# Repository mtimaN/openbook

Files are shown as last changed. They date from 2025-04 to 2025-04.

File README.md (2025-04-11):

# openbook
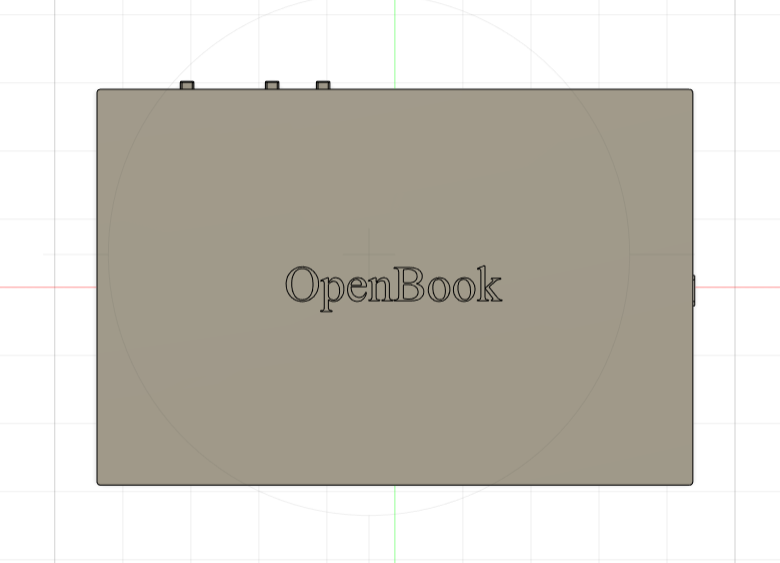
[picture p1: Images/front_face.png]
front_face

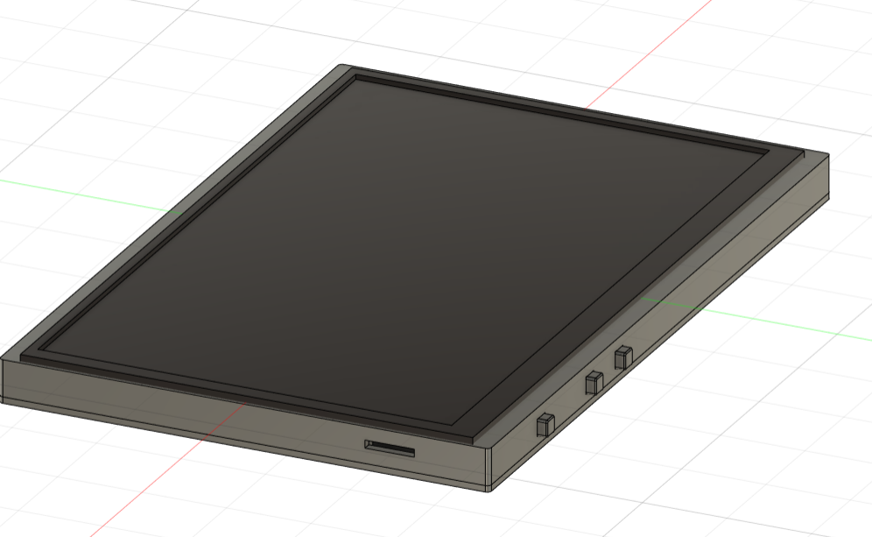
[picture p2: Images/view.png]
pretty_pic


## Overview
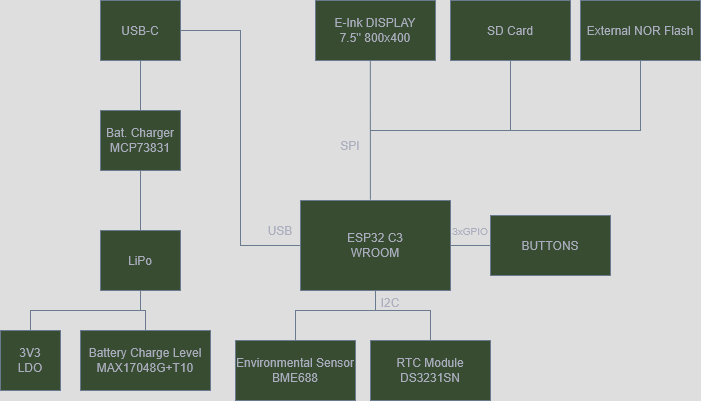
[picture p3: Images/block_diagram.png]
block_diagram


# 📚 eBook Reader – System Overview

This project is an eBook reader based on the ESP32-C3 microcontroller. It features a 7.5" E-Ink display, SD card storage, environmental sensing, and a rechargeable LiPo battery, all optimized for low power consumption and readability.

### **ESP32-C3 WROOM**
The main microcontroller that handles:
- Display updates via **SPI**
- File system and memory management
- Button inputs through **GPIO**
- Communication with sensors and RTC via **I2C**
- USB communication for firmware updates or data transfer

### **E-Ink DISPLAY 7.5" 800x400**
- Ultra-low power display ideal for reading in bright light
- Interface: SPI
- Controlled by the ESP32 for rendering text and images

###  Storage

- **SD Card**: Stores eBooks and data files
- **External NOR Flash**: Used for firmware, fonts, or static assets

### Power Management

- **USB-C**: Input for charging and potential USB data connection
- **Battery Charger (MCP73831)**: Manages LiPo charging
- **LiPo Battery**: Powers the system when unplugged
- **Battery Level Monitor (MAX17048G+T10)**: Reports battery percentage to the ESP32
- **3V3 LDO Regulator**: Provides stable 3.3V for the system

### **BME688 Sensor**
- Measures:
  - Temperature
  - Humidity
  - Pressure
  - Air quality
- Data can be displayed or logged for contextual awareness

### **DS3231SN RTC Module**
- Keeps track of time even when powered off
- Useful for:
  - Timestamps
  - Scheduled wake-ups
  - Time-based features
## ⚡ Energy Usage Overview

Estimated average current during typical reading:

| Component | Avg Current | Notes |
|---|---|---|
| ESP32-C3 | ~2 mA | Light sleep + brief active use |
| E-Ink Display | ~1–2 mA | Only draws power during refresh |
| SD Card | ~1 mA | Accessed briefly per page turn |
| BME688 Sensor | ~0.15 mA | In low-power mode |
| RTC DS3231SN | ~0.002 mA | Always running |
| Battery Monitor  | ~0.05 mA | Very low power |
| **Total** | **~5.2 mA** | Approximate average current |

With a **1200 mAh LiPo battery**:
- **Estimated runtime:** ~**9 days** of light usage
- Based on 1 screen update per minute, minimal background activity

## Bill of Materials (BOM) 
|SAMACSYS_PARTS_USB4110GFA|Value |Device |Detailed Description |Link |
|---|---|---|---|---|
|BOOT_BUTTON |BUTTON_CUSYOMV1 |BUTTON_CUSYOMV1 | |https://industry.panasonic.com/global/en/products/control/switch/light-touch/number/evqpuj02k |
|C1 |100nF |ESP32_WROVER_EAGLE-LTSPICE_CC0402 |CAPACITOR, European symbol |https://ro.mouser.com/ProductDetail/KYOCERA-AVX/12107C104KAT2A?qs=%252BdQmOuGyFcEpzvTfYF11Tg%3D%3D |
|C1_BAT |4.7uF |ESP32_WROVER_EAGLE-LTSPICE_CC0402 |CAPACITOR, European symbol |https://ro.mouser.com/ProductDetail/KYOCERA-AVX/12107C104KAT2A?qs=%252BdQmOuGyFcEpzvTfYF11Tg%3D%3D |
|C1_BAT1 |4.7uF |ESP32_WROVER_EAGLE-LTSPICE_CC0402 |CAPACITOR, European symbol |https://ro.mouser.com/ProductDetail/KYOCERA-AVX/12107C104KAT2A?qs=%252BdQmOuGyFcEpzvTfYF11Tg%3D%3D |
|C1_BAT2 |4.7uF |EAGLE-LTSPICE_CC0402 |CAPACITOR, European symbol |https://ro.mouser.com/ProductDetail/KYOCERA-AVX/12107C104KAT2A?qs=%252BdQmOuGyFcEpzvTfYF11Tg%3D%3D |
|C2 |100nF |ESP32_WROVER_EAGLE-LTSPICE_CC0402 |CAPACITOR, European symbol |https://ro.mouser.com/ProductDetail/KYOCERA-AVX/12107C104KAT2A?qs=%252BdQmOuGyFcEpzvTfYF11Tg%3D%3D |
|C2_BAT |4.7uF |ESP32_WROVER_EAGLE-LTSPICE_CC0402 |CAPACITOR, European symbol |https://ro.mouser.com/ProductDetail/KYOCERA-AVX/12107C104KAT2A?qs=%252BdQmOuGyFcEpzvTfYF11Tg%3D%3D |
|C3 |100uF TANT |RCL_CPOL-EUCT3528 |POLARIZED CAPACITOR, European symbol |https://ro.mouser.com/ProductDetail/Panasonic/EEU-FS1K101L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 |
|C4 |4.7uF/25V |ESP32_WROVER_EAGLE-LTSPICE_CC0402 |CAPACITOR, European symbol |https://ro.mouser.com/ProductDetail/KYOCERA-AVX/12107C104KAT2A?qs=%252BdQmOuGyFcEpzvTfYF11Tg%3D%3D |
|C4_USB |100nF |ESP32_WROVER_EAGLE-LTSPICE_CC0402 |CAPACITOR, European symbol |https://ro.mouser.com/ProductDetail/KYOCERA-AVX/12107C104KAT2A?qs=%252BdQmOuGyFcEpzvTfYF11Tg%3D%3D |
|C5 |1uF |ESP32_WROVER_EAGLE-LTSPICE_CC0402 |CAPACITOR, European symbol |https://ro.mouser.com/ProductDetail/KYOCERA-AVX/12107C104KAT2A?qs=%252BdQmOuGyFcEpzvTfYF11Tg%3D%3D |
|C5_USB |4.7uF |ESP32_WROVER_EAGLE-LTSPICE_CC0402 |CAPACITOR, European symbol |https://ro.mouser.com/ProductDetail/KYOCERA-AVX/12107C104KAT2A?qs=%252BdQmOuGyFcEpzvTfYF11Tg%3D%3D |
|C6 |100nF |ESP32_WROVER_EAGLE-LTSPICE_CC0402 |CAPACITOR, European symbol |https://ro.mouser.com/ProductDetail/KYOCERA-AVX/12107C104KAT2A?qs=%252BdQmOuGyFcEpzvTfYF11Tg%3D%3D |
|C7 |10uF |ESP32_WROVER_EAGLE-LTSPICE_CC0402 |CAPACITOR, European symbol |https://ro.mouser.com/ProductDetail/KYOCERA-AVX/12107C104KAT2A?qs=%252BdQmOuGyFcEpzvTfYF11Tg%3D%3D |
|C8 |100nF |ESP32_WROVER_EAGLE-LTSPICE_CC0402 |CAPACITOR, European symbol |https://ro.mouser.com/ProductDetail/KYOCERA-AVX/12107C104KAT2A?qs=%252BdQmOuGyFcEpzvTfYF11Tg%3D%3D |
|C9 |100nF |EAGLE-LTSPICE_CC0402 |CAPACITOR, European symbol |https://ro.mouser.com/ProductDetail/KYOCERA-AVX/12107C104KAT2A?qs=%252BdQmOuGyFcEpzvTfYF11Tg%3D%3D |
|C10 |100nF |ESP32_WROVER_EAGLE-LTSPICE_CC0402 |CAPACITOR, European symbol |https://ro.mouser.com/ProductDetail/KYOCERA-AVX/12107C104KAT2A?qs=%252BdQmOuGyFcEpzvTfYF11Tg%3D%3D |
|C10_SUPERCAP |CPH3225A |CPH3225A |Cap 0.011F 3.3V 1210 Flat |https://ro.mouser.com/ProductDetail/Seiko-Semiconductors/CPH3225A?qs=3etwrb1wR%252BhUOph6lAO7eg%3D%3D |
|CHANGE_BUTTON |BUTTON_CUSYOMV1 |BUTTON_CUSYOMV1 | |https://industry.panasonic.com/global/en/products/control/switch/light-touch/number/evqpuj02k |
|CHG_LED | |ADAFRUIT_LEDCHIP-LED0603 |LED |https://ro.mouser.com/ProductDetail/BJB/35.116.1007-001-01?qs=iLKYxzqNS76jqQb6thkyzg%3D%3D |
|C_DELAY |100nF |ESP32_WROVER_EAGLE-LTSPICE_CC0402 |CAPACITOR, European symbol |https://ro.mouser.com/ProductDetail/KYOCERA-AVX/12107C104KAT2A?qs=%252BdQmOuGyFcEpzvTfYF11Tg%3D%3D |
|D1 |USBLC6-2SC6Y |USBLC6-2SC6Y |Low Cap. ESD Protection Auto SOT-23-6 STMicroelectronics USBLC6-2SC6Y, Dual Uni-Directional TVS Diode Array, 6-Pin SOT-23 |https://ro.mouser.com/ProductDetail/Nexperia/PMEG6030AEXEX?qs=olJun0bQHM8zqhEtOgE2ZA%3D%3D |
|D2 |ESP32_WROVER_AVX---SD0805S020S1R0_AVX_SD0805S020S1R0_0_0AVX_SD0805S020S1R0_0_0|ESP32_WROVER_AVX---SD0805S020S1R0_AVX_SD0805S020S1R0_0_0AVX_SD0805S020S1R0_0_0|Schottky Barrier Rectifier Diode |https://ro.mouser.com/ProductDetail/Nexperia/PMEG6030AEXEX?qs=olJun0bQHM8zqhEtOgE2ZA%3D%3D |
|D3 |MBR0530 |MBR0530 |ON SEMICONDUCTOR - MBR0530 - DIODE, SCHOTTKY, 0.5A, 30V, SOD-123 |https://ro.mouser.com/ProductDetail/Nexperia/PMEG6030AEXEX?qs=olJun0bQHM8zqhEtOgE2ZA%3D%3D |
|D4 |MBR0530 |MBR0530 |ON SEMICONDUCTOR - MBR0530 - DIODE, SCHOTTKY, 0.5A, 30V, SOD-123 |https://ro.mouser.com/ProductDetail/Nexperia/PMEG6030AEXEX?qs=olJun0bQHM8zqhEtOgE2ZA%3D%3D |
|D5 |MBR0530 |MBR0530 |ON SEMICONDUCTOR - MBR0530 - DIODE, SCHOTTKY, 0.5A, 30V, SOD-123 |https://ro.mouser.com/ProductDetail/Nexperia/PMEG6030AEXEX?qs=olJun0bQHM8zqhEtOgE2ZA%3D%3D |
|D6 |PGB1010603MR |PGB1010603MR |Check availability |https://ro.mouser.com/ProductDetail/Nexperia/PMEG6030AEXEX?qs=olJun0bQHM8zqhEtOgE2ZA%3D%3D |
|D7 |ESP32_WROVER_AVX---SD0805S020S1R0_AVX_SD0805S020S1R0_0_0AVX_SD0805S020S1R0_0_0|ESP32_WROVER_AVX---SD0805S020S1R0_AVX_SD0805S020S1R0_0_0AVX_SD0805S020S1R0_0_0|Schottky Barrier Rectifier Diode |https://ro.mouser.com/ProductDetail/Nexperia/PMEG6030AEXEX?qs=olJun0bQHM8zqhEtOgE2ZA%3D%3D |
|D8 |PGB1010603MR |PGB1010603MR |Schottky Barrier Rectifier Diode |https://ro.mouser.com/ProductDetail/Nexperia/PMEG6030AEXEX?qs=olJun0bQHM8zqhEtOgE2ZA%3D%3D |
|D9 |PGB1010603MR |PGB1010603MR |Schottky Barrier Rectifier Diode |https://ro.mouser.com/ProductDetail/Nexperia/PMEG6030AEXEX?qs=olJun0bQHM8zqhEtOgE2ZA%3D%3D |
|D10 |PGB1010603MR |PGB1010603MR |Schottky Barrier Rectifier Diode |https://ro.mouser.com/ProductDetail/Nexperia/PMEG6030AEXEX?qs=olJun0bQHM8zqhEtOgE2ZA%3D%3D |
|D11 |PGB1010603MR |PGB1010603MR |Schottky Barrier Rectifier Diode |https://ro.mouser.com/ProductDetail/Nexperia/PMEG6030AEXEX?qs=olJun0bQHM8zqhEtOgE2ZA%3D%3D |
|D12 |PGB1010603MR |PGB1010603MR |Schottky Barrier Rectifier Diode |https://ro.mouser.com/ProductDetail/Nexperia/PMEG6030AEXEX?qs=olJun0bQHM8zqhEtOgE2ZA%3D%3D |
|EPD_C1 |1uF/50V |ESP32_WROVER_EAGLE-LTSPICE_CC0402 |CAPACITOR, European symbol |https://ro.mouser.com/ProductDetail/KEMET/MMK10105K50A01L4BULK?qs=IKDMbYZLynBqWdM%252BAUSFtw%3D%3D |
|EPD_C2 |1uF/50V |ESP32_WROVER_EAGLE-LTSPICE_CC0402 |CAPACITOR, European symbol |https://ro.mouser.com/ProductDetail/KEMET/MMK10105K50A01L4BULK?qs=IKDMbYZLynBqWdM%252BAUSFtw%3D%3D |
|EPD_C5 |1uF/50V |ESP32_WROVER_EAGLE-LTSPICE_CC0402 |CAPACITOR, European symbol |https://ro.mouser.com/ProductDetail/KEMET/MMK10105K50A01L4BULK?qs=IKDMbYZLynBqWdM%252BAUSFtw%3D%3D |
|EPD_C6 |1uF/50V |ESP32_WROVER_EAGLE-LTSPICE_CC0402 |CAPACITOR, European symbol |https://ro.mouser.com/ProductDetail/KEMET/MMK10105K50A01L4BULK?qs=IKDMbYZLynBqWdM%252BAUSFtw%3D%3D |
|EPD_C7 |1uF/50V |ESP32_WROVER_EAGLE-LTSPICE_CC0402 |CAPACITOR, European symbol |https://ro.mouser.com/ProductDetail/KEMET/MMK10105K50A01L4BULK?qs=IKDMbYZLynBqWdM%252BAUSFtw%3D%3D |
|EPD_C8 |1uF/50V |ESP32_WROVER_EAGLE-LTSPICE_CC0402 |CAPACITOR, European symbol |https://ro.mouser.com/ProductDetail/KEMET/MMK10105K50A01L4BULK?qs=IKDMbYZLynBqWdM%252BAUSFtw%3D%3D |
|EPD_C9 |1uF/50V |ESP32_WROVER_EAGLE-LTSPICE_CC0402 |CAPACITOR, European symbol |https://ro.mouser.com/ProductDetail/KEMET/MMK10105K50A01L4BULK?qs=IKDMbYZLynBqWdM%252BAUSFtw%3D%3D |
|EPD_C10 |1uF/50V |ESP32_WROVER_EAGLE-LTSPICE_CC0402 |CAPACITOR, European symbol |https://ro.mouser.com/ProductDetail/KEMET/MMK10105K50A01L4BULK?qs=IKDMbYZLynBqWdM%252BAUSFtw%3D%3D |
|EPD_C11 |1uF/50V |ESP32_WROVER_EAGLE-LTSPICE_CC0402 |CAPACITOR, European symbol |https://ro.mouser.com/ProductDetail/KEMET/MMK10105K50A01L4BULK?qs=IKDMbYZLynBqWdM%252BAUSFtw%3D%3D |
|EPD_C12 |1uF/50V |ESP32_WROVER_EAGLE-LTSPICE_CC0402 |CAPACITOR, European symbol |https://ro.mouser.com/ProductDetail/KEMET/MMK10105K50A01L4BULK?qs=IKDMbYZLynBqWdM%252BAUSFtw%3D%3D |
|IC1 |BD5229G-TR |BD5229G-TR |Voltage Detector with Adjustable Delay Time: CMOS processes are utilized to develop high precision, low current consumption CMOS reset ICs that allow arbitrary setting of the delay time. The extensive lineup includes both Nch Open Drain and CMOS output types in a wide range of detection voltages (from 2.3V to 6.0V, in 0.1V steps), enabling selection of the ideal solution based on customer requirements. In addition, the entire series is of course both lead-free and RoHS-compliant.|https://ro.mouser.com/ProductDetail/ROHM-Semiconductor/BD5229G-TR?qs=4kLU8WoGk0vvnhrrYwdszw%3D%3D |
|IC4 |XC6220A331MR-G |XC6220A331MR-G |LDO Voltage Regulators | |
|J1 |FH34SRJ-24S-0.5SH_99_ |FH34SRJ-24S-0.5SH_99_ |24 Position FFC, FPC Connector Contacts, Top and Bottom 0.020 (0.50mm) Surface Mount, Right Angle" | |
|J2 |SAMACSYS_PARTS_USB4110-GF-A |SAMACSYS_PARTS_USB4110-GF-A |CONN USB 2.0 TYPE-C R/A SMT | |
|J3 |QWIIC_RIGHT_ANGLE |QWIIC_CONNECTORJS-1MM |SparkFun I2C Standard Qwiic Connector | |
|J4 |112A-TAAR-R03_ATTEND |112A-TAAR-R03_ATTEND |Micro SD Card Socket, Push-Push Type, Top Mount, SMT, H=1.83mm, 10u | |
|L1 |68uH |744043680IND_4828-WE-TPC_WRE | | |
|PFMF.050.1 |ESP32C6_VARISTORCN1812 |ESP32C6_VARISTORCN1812 |VARISTOR | |
|Q1 |20V/4.2A/52mO/1.4W |ESP32_WROVER_SPARKFUN-DISCRETESEMI_MOSFET_PCH-DMG2305UX-7 |P-channel MOSFETs | |
|Q2 |20V/4.2A/52mO/1.4W |ESP32_WROVER_SPARKFUN-DISCRETESEMI_MOSFET_PCH-DMG2305UX-7 |P-channel MOSFETs |https://ro.mouser.com/ProductDetail/Vishay-Siliconix/SQ3425CEV-T1_GE3?qs=i8QVZAFTkqQazbKSzWc2Vg%3D%3D |
|Q3 |SI1308EDL-T1-GE3 |SI1308EDL-T1-GE3 |MOSFET N-Ch 30V 1.5A TrenchFET SC70 Vishay Si1308EDL-T1-GE3 N-channel MOSFET Transistor, 1.5 A, 30 V, 3-Pin SC-70 |https://ro.mouser.com/ProductDetail/Vishay-Semiconductors/SI1308EDL-T1-GE3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 |
|R1 |10K |ESP32_WROVER_EAGLE-LTSPICE_RR0402 |RESISTOR, European symbol |https://ro.mouser.com/ProductDetail/Vishay-Beyschlag/MCS0402MD4703BE500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|
|R1-PINH |10K |ESP32_WROVER_EAGLE-LTSPICE_RR0402 |RESISTOR, European symbol |https://ro.mouser.com/ProductDetail/Vishay-Beyschlag/MCS0402MD4703BE500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|
|R1-PINH1 |10K |ESP32_WROVER_EAGLE-LTSPICE_RR0402 |RESISTOR, European symbol |https://ro.mouser.com/ProductDetail/Vishay-Beyschlag/MCS0402MD4703BE500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|
|R1_BAT |200 |ESP32_WROVER_EAGLE-LTSPICE_RR0402 |RESISTOR, European symbol |https://ro.mouser.com/ProductDetail/Vishay-Beyschlag/MCS0402MD4703BE500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|
|R1_PWRUSB |100K |ESP32_WROVER_EAGLE-LTSPICE_RR0402 |RESISTOR, European symbol |https://ro.mouser.com/ProductDetail/Vishay-Beyschlag/MCS0402MD4703BE500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|
|R2 |2.2 |ESP32_WROVER_EAGLE-LTSPICE_RR0402 |RESISTOR, European symbol |https://ro.mouser.com/ProductDetail/Vishay-Beyschlag/MCS0402MD4703BE500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|
|R2-PINH |10K |ESP32_WROVER_EAGLE-LTSPICE_RR0402 |RESISTOR, European symbol |https://ro.mouser.com/ProductDetail/Vishay-Beyschlag/MCS0402MD4703BE500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|
|R2-PINH1 |10K |ESP32_WROVER_EAGLE-LTSPICE_RR0402 |RESISTOR, European symbol |https://ro.mouser.com/ProductDetail/Vishay-Beyschlag/MCS0402MD4703BE500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|
|R2-USB |5k1 |ESP32_WROVER_EAGLE-LTSPICE_RR0402 |RESISTOR, European symbol |https://ro.mouser.com/ProductDetail/Vishay-Beyschlag/MCS0402MD4703BE500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|
|R2-USB1 |5k1 |ESP32_WROVER_EAGLE-LTSPICE_RR0402 |RESISTOR, European symbol |https://ro.mouser.com/ProductDetail/Vishay-Beyschlag/MCS0402MD4703BE500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|
|R2_BAT |2K |ESP32_WROVER_EAGLE-LTSPICE_RR0402 |RESISTOR, European symbol |https://ro.mouser.com/ProductDetail/Vishay-Beyschlag/MCS0402MD4703BE500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|
|R3 |10K |ESP32_WROVER_EAGLE-LTSPICE_RR0402 |RESISTOR, European symbol |https://ro.mouser.com/ProductDetail/Vishay-Beyschlag/MCS0402MD4703BE500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|
|R4 |10K |ESP32_WROVER_EAGLE-LTSPICE_RR0402 |RESISTOR, European symbol |https://ro.mouser.com/ProductDetail/Vishay-Beyschlag/MCS0402MD4703BE500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|
|R5 |10K |ESP32_WROVER_EAGLE-LTSPICE_RR0402 |RESISTOR, European symbol |https://ro.mouser.com/ProductDetail/Vishay-Beyschlag/MCS0402MD4703BE500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|
|R6 |10K |ESP32_WROVER_EAGLE-LTSPICE_RR0402 |RESISTOR, European symbol |https://ro.mouser.com/ProductDetail/Vishay-Beyschlag/MCS0402MD4703BE500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|
|R7 |10K |ESP32_WROVER_EAGLE-LTSPICE_RR0402 |RESISTOR, European symbol |https://ro.mouser.com/ProductDetail/Vishay-Beyschlag/MCS0402MD4703BE500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|
|R8 |10K |ESP32_WROVER_EAGLE-LTSPICE_RR0402 |RESISTOR, European symbol |https://ro.mouser.com/ProductDetail/Vishay-Beyschlag/MCS0402MD4703BE500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|
|R9 |10K |ESP32_WROVER_EAGLE-LTSPICE_RR0402 |RESISTOR, European symbol |https://ro.mouser.com/ProductDetail/Vishay-Beyschlag/MCS0402MD4703BE500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|
|R10 |10K |ESP32_WROVER_EAGLE-LTSPICE_RR0402 |RESISTOR, European symbol |https://ro.mouser.com/ProductDetail/Vishay-Beyschlag/MCS0402MD4703BE500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|
|RESET_BUTTON |BUTTON_CUSYOMV1 |BUTTON_CUSYOMV1 | |https://industry.panasonic.com/global/en/products/control/switch/light-touch/number/evqpuj02k |
|R_BOOT |10K |ESP32_WROVER_EAGLE-LTSPICE_RR0402 |RESISTOR, European symbol |https://ro.mouser.com/ProductDetail/Vishay-Beyschlag/MCS0402MD4703BE500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|
|R_CAPACITOR |15 |ESP32_WROVER_EAGLE-LTSPICE_RR0402 |RESISTOR, European symbol |https://ro.mouser.com/ProductDetail/Vishay-Beyschlag/MCS0402MD4703BE500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|
|R_CHANGE |10K |ESP32_WROVER_EAGLE-LTSPICE_RR0402 |RESISTOR, European symbol |https://ro.mouser.com/ProductDetail/Vishay-Beyschlag/MCS0402MD4703BE500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|
|R_CL1 |10K |ESP32_WROVER_EAGLE-LTSPICE_RR0402 |RESISTOR, European symbol |https://ro.mouser.com/ProductDetail/Vishay-Beyschlag/MCS0402MD4703BE500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|
|R_RESET |10K |ESP32_WROVER_EAGLE-LTSPICE_RR0402 |RESISTOR, European symbol |https://ro.mouser.com/ProductDetail/Vishay-Beyschlag/MCS0402MD4703BE500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|
|SENSOR2 | |ESP32_WROVER_BME680_BME680 |Integrated Environmental Unit |https://ro.mouser.com/ProductDetail/Bosch-Sensortec/BME680?qs=v271MhAjFHjo0yA%2FC4OnDQ%3D%3D |
|SJ1 | |SJ |SMD solder JUMPER |https://ro.mouser.com/ProductDetail/Nidec-Components/CJS-1201B?qs=XeJtXLiO41SSSa2Z7HG9Iw%3D%3D |
|TP1 |TPTP20R |TPTP20R |Test pad | |
|TP2 |TPTP20R |TPTP20R |Test pad | |
|TP3 |TPTP20R |TPTP20R |Test pad | |
|TP4 |TPTP20R |TPTP20R |Test pad | |
|TP5 |TPTP20R |TPTP20R |Test pad | |
|TP6 |TPTP20R |TPTP20R |Test pad | |
|TP7 |TPTP20R |TPTP20R |Test pad | |
|TP8 |TPTP20R |TPTP20R |Test pad | |
|TP9 |TPTP20R |TPTP20R |Test pad | |
|TP10 |TPTP20R |TPTP20R |Test pad | |
|TP11 |TPTP20R |TPTP20R |Test pad | |
|TP12 |TPTP20R |TPTP20R |Test pad | |
|TP13 |TPTP20R |TPTP20R |Test pad | |
|TP14 |TPTP20R |TPTP20R |Test pad | |
|TP15 |TPTP20R |TPTP20R |Test pad | |
|TP16 |TPTP20R |TPTP20R |Test pad | |
|TP17 |TPTP20R |TPTP20R |Test pad | |
|U1 |W25Q512JVEIQ |W25Q512JVEIQ | |https://ro.mouser.com/ProductDetail/Winbond/W25Q512JVEIQ?qs=l7cgNqFNU1jw6svr3at6tA%3D%3D |
|U2 |ESP32-C6-WROOM-1-N8 |ESP32-C6-WROOM-1-N8 | |https://ro.mouser.com/ProductDetail/Espressif-Systems/ESP32-C6-WROOM-1-N8?qs=8Wlm6%252BaMh8ST02Gmwp74cw%3D%3D |
|U3 |DS3231SN# |DS3231SN# | |https://ro.mouser.com/ProductDetail/Analog-Devices-Maxim-Integrated/DS3231SN?qs=1eQvB6Dk1vhUlr8%2FOrV0Fw%3D%3D |
|U4 |MAX17048G+T10 |MAX17048G+T10 | |https://ro.mouser.com/ProductDetail/Analog-Devices-Maxim-Integrated/MAX17048G%2bT10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 |
|U5 |MCP73831 |ESP32_WROVER_SPARKFUN-IC-POWER_MCP73831 |MCP73831T Li-Ion, Li-Pol Controller |https://ro.mouser.com/ProductDetail/Microchip-Technology/MCP73831T-2ACI-OT?qs=yUQqVecv4qvbBQBGbHx0Mw%3D%3D |

## Detailed description
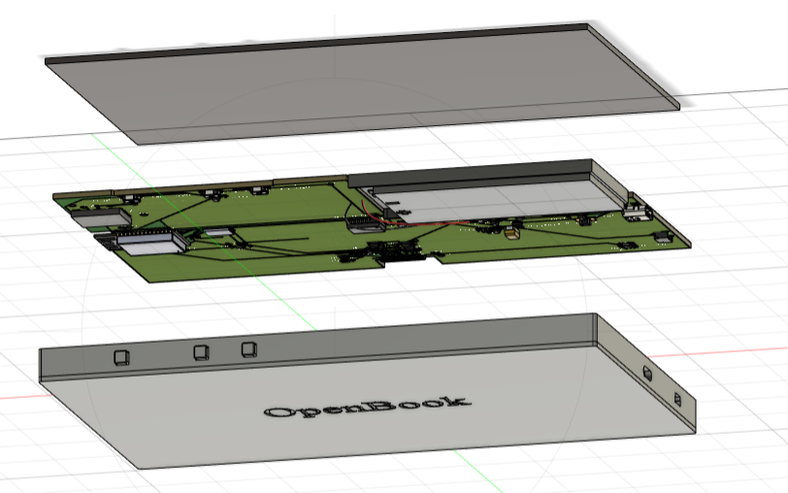
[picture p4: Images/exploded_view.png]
exploded_view


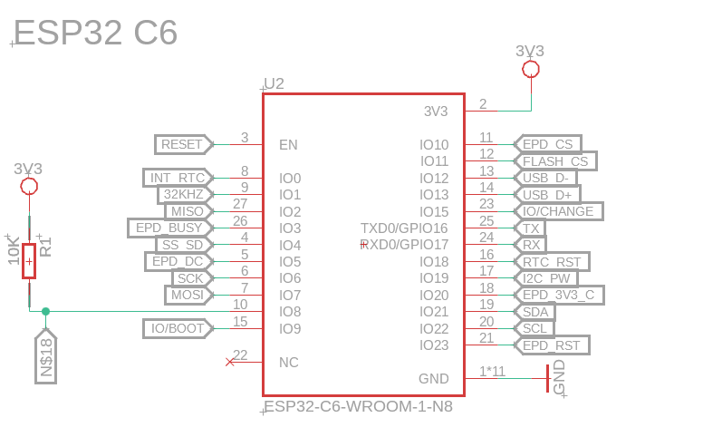
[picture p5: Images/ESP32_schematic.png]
esp32

- Resistor (R1) connected to GPIO8: This is a pull-up resistor connected to GPIO8. Pull-up resistors are used to ensure a pin has a defined high state when no external signal is applied.
- GPIO8: This is a general-purpose input/output pin. It can be configured as either an input or an output.
- IO/BOOT (Pin 15): This pin is used to put the ESP32-C6 into bootloader mode, which is necessary for flashing firmware.
- NC (Pin 22): This stands for "No Connection." This pin is not connected to anything in this particular circuit.
- EN (Pin 3): This is the Enable pin. Pulling this pin low resets the ESP32-C6.
- INT_RTC (Pin 8): This is likely an interrupt pin related to the Real-Time Clock (RTC) functionality.
- 32KHz (Pin 9): This is probably the input for a 32.768 kHz crystal oscillator, which is used for the RTC.
- MISO (Pin 27): This is the Master In Slave Out pin for the SPI (Serial Peripheral Interface) communication protocol.
- EPD_BUSY (Pin 4): This pin is likely used to signal the busy state of an E-Paper Display (EPD).
- SS_SD (Pin 5): This is the Slave Select pin for the SD card interface.
- EPD_DC (Pin 6): This is the Data/Command pin for the EPD.
- SCK (Pin 7): This is the Serial Clock pin for SPI communication.
- MOSI (Pin 10): This is the Master Out Slave In pin for SPI communication.
- 3V3 (Pin 2): This is another 3.3V power supply pin.
- IO10 to IO15 (Pins 11-14, 23): These are general-purpose input/output pins.
- TXD0/GPIO16 (Pin 24): This is the transmit pin for UART0 (Universal Asynchronous Receiver/Transmitter) and also functions as GPIO16.
- RXD0/GPIO17 (Pin 25): This is the receive pin for UART0 and also functions as GPIO17.
- RX (Pin 16): This is likely another receive pin, possibly for a second UART.
- RTC_RST (Pin 17): This is the reset pin for the RTC.
- I2C_PW (Pin 12): This pin might be related to powering the I2C (Inter-Integrated Circuit) bus.
- IO18 to IO23 (Pins 18-21): These are general-purpose input/output pins.
- EPD_3V3_C (Pin 19): This is likely a 3.3V power supply pin specifically for the EPD.
- SDA (Pin 20): This is the Serial Data pin for I2C communication.
- SCL (Pin 21): This is the Serial Clock pin for I2C communication.
- EPD_RST (Pin 21): This is the reset pin for the EPD.
- 1*11 (Pin 1): This indicates that pin 1 is connected to ground (GND).

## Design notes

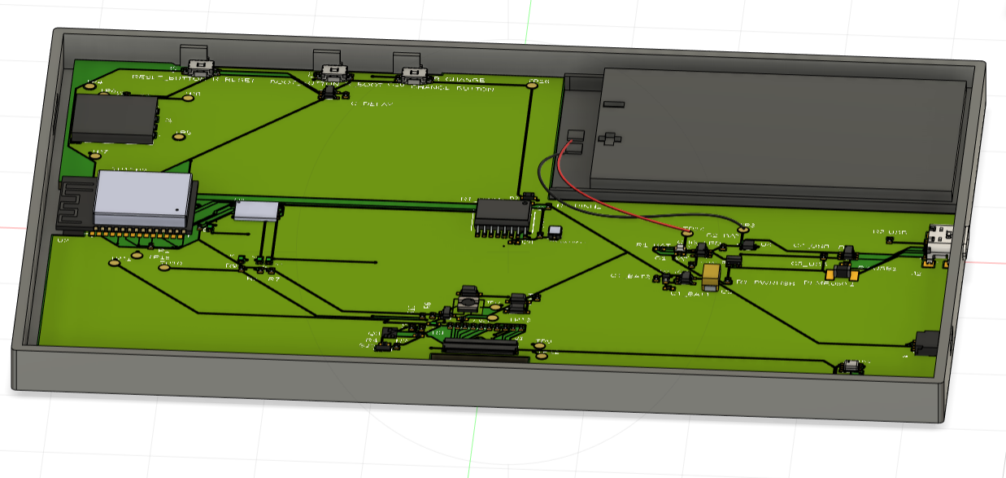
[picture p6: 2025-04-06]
Images/inside_view.png

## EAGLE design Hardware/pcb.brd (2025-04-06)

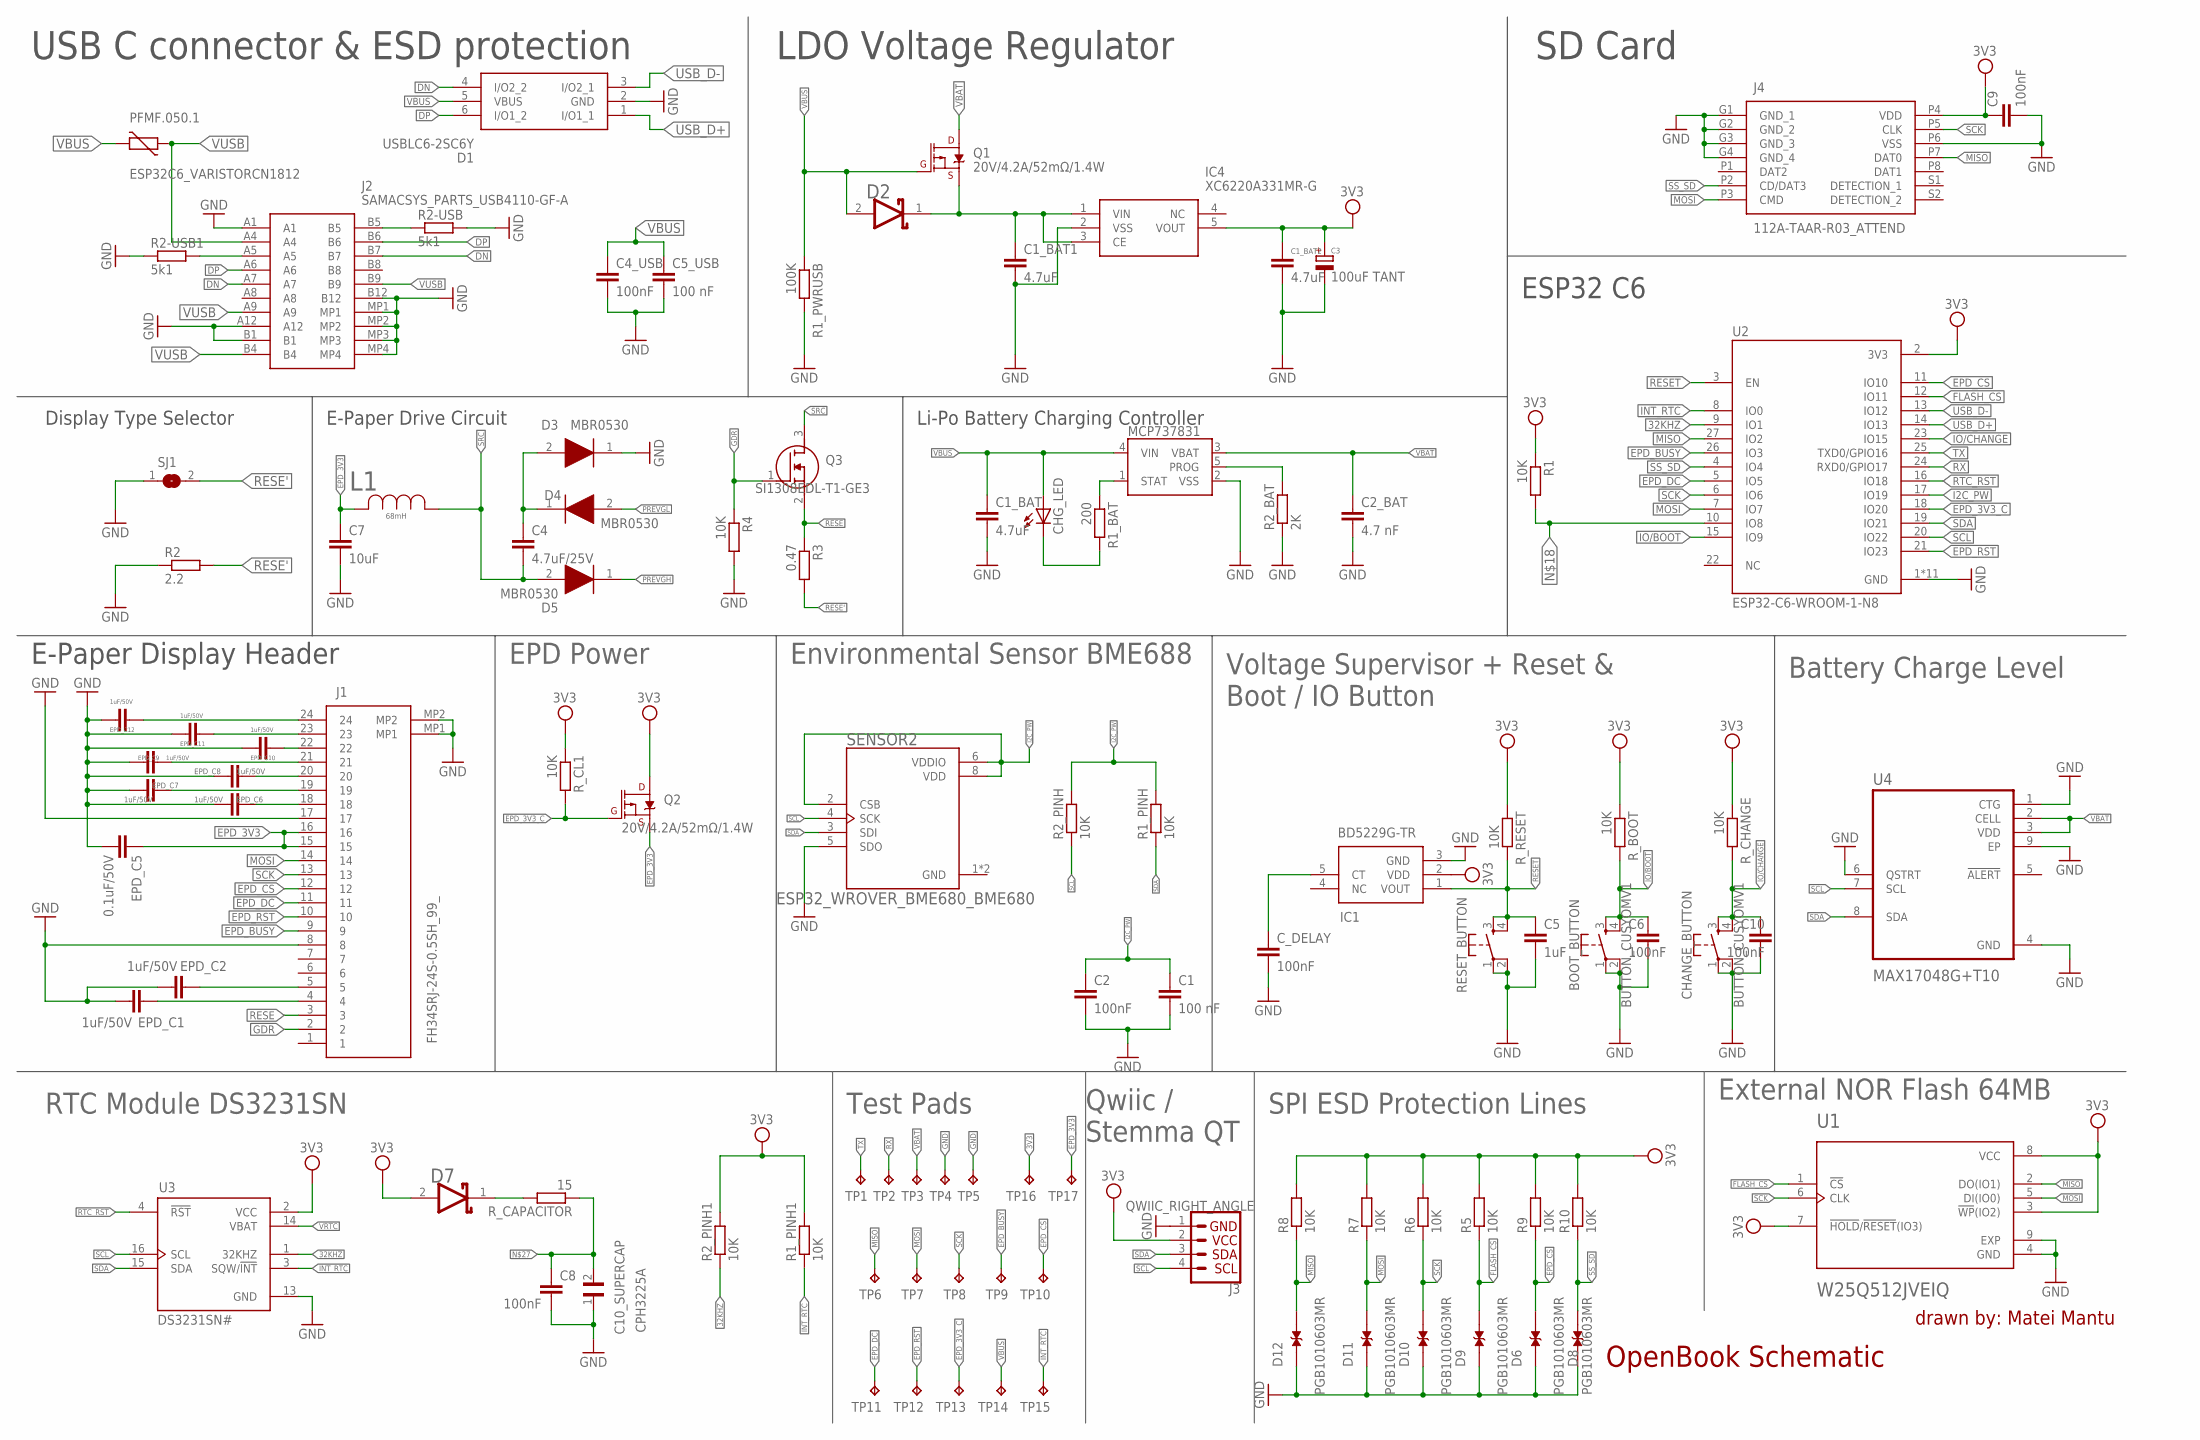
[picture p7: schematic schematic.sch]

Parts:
BOOT_BUTTON: BUTTON_CUSYOMV1; MYBUTTON
C1, C5_USB: 100 nF; EAGLE-LTSPICE_C0402
C1_BAT, C1_BAT1, C1_BAT2: 4.7uF; EAGLE-LTSPICE_C0402
C2, C4_USB, C6, C8, C9, C10: 100nF; EAGLE-LTSPICE_C0402
C2_BAT: 4.7 nF; EAGLE-LTSPICE_C0402
C3: 100uF TANT; RCL_CT3528
C4: 4.7uF/25V; EAGLE-LTSPICE_C0402
C5: 1uF; EAGLE-LTSPICE_C0402
C7: 10uF; EAGLE-LTSPICE_C0402
C10_SUPERCAP: CPH3225A; CAPCP3225X100N
CHANGE_BUTTON: BUTTON_CUSYOMV1; MYBUTTON
CHG_LED: ADAFRUIT_LEDCHIP-LED0603; ADAFRUIT_CHIP-LED0603
C_DELAY: 100nF; EAGLE-LTSPICE_C0402
D1: USBLC6-2SC6Y; SOT95P280X145-6N
D2, D7: ESP32_WROVER_AVX---SD0805S020S1R0_AVX_SD0805S020S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; ESP32_WROVER_AVX---SD0805S020S1R0_AVX_SD0805S020S1R0_0
D3, D4, D5: MBR0530; SOD3716X135N
D6, D8, D9, D10, D11, D12: PGB1010603MR; DIOC1608X36N
EPD_C1, EPD_C2, EPD_C6, EPD_C7, EPD_C8, EPD_C9, EPD_C10, EPD_C11, EPD_C12: 1uF/50V; EAGLE-LTSPICE_C0402
EPD_C5: 0.1uF/50V; EAGLE-LTSPICE_C0402
IC1: BD5229G-TR; SOT95P280X125-5N
IC4: XC6220A331MR-G; SOT95P280X120-5N
J1: FH34SRJ-24S-0.5SH_99_; FH34SRJ24S05SH99
J2: SAMACSYS_PARTS_USB4110-GF-A; SAMACSYS_PARTS_USB4110GFA
J3: QWIIC_RIGHT_ANGLE; JST04_1MM_RA
J4: 112A-TAAR-R03_ATTEND; 112ATAARR03ATTEND
L1: 68mH; IND_4828-WE-TPC_WRE
MCP737831: ESP32_WROVER_SPARKFUN-IC-POWER_MCP73831; ESP32_WROVER_SPARKFUN-IC-POWER_SOT23-5
PFMF.050.1: ESP32C6_VARISTORCN1812; ESP32C6_VARISTOR_CT/CN1812
Q1, Q2: 20V/4.2A/52mΩ/1.4W; ESP32_WROVER_SPARKFUN-DISCRETESEMI_SOT23-3
Q3: SI1308EDL-T1-GE3; SOT65P210X110-3N
R1, R1_PINH, R1_PINH1, R2_PINH, R2_PINH1, R4, R5, R6, R7, R8, R9, R10: 10K; ESP32_WROVER_EAGLE-LTSPICE_R0402
R1_BAT: 200; ESP32_WROVER_EAGLE-LTSPICE_R0402
R1_PWRUSB: 100K; ESP32_WROVER_EAGLE-LTSPICE_R0402
R2: 2.2; ESP32_WROVER_EAGLE-LTSPICE_R0402
R2-USB, R2-USB1: 5k1; ESP32_WROVER_EAGLE-LTSPICE_R0402
R2_BAT: 2K; ESP32_WROVER_EAGLE-LTSPICE_R0402
R3: 0.47; ESP32_WROVER_EAGLE-LTSPICE_R0402
RESET_BUTTON: BUTTON_CUSYOMV1; MYBUTTON
R_BOOT: 10K; ESP32_WROVER_EAGLE-LTSPICE_R0402
R_CAPACITOR: 15; ESP32_WROVER_EAGLE-LTSPICE_R0402
R_CHANGE: 10K; ESP32_WROVER_EAGLE-LTSPICE_R0402
R_CL1: 10K; ESP32_WROVER_EAGLE-LTSPICE_R0402
R_RESET: 10K; ESP32_WROVER_EAGLE-LTSPICE_R0402
SENSOR2: ESP32_WROVER_BME680_BME680; ESP32_WROVER_BME680_PSON80P300X300X100-8N
SJ1: SJ
TP1, TP2, TP3, TP4, TP5, TP6, TP7, TP8, TP9, TP10, TP11, TP12, TP13, TP14, TP15, TP16, TP17: TPTP20R; TP20R
U1: W25Q512JVEIQ; SON127P600X800X80-9N
U2: ESP32-C6-WROOM-1-N8; XCVR_ESP32-C6-WROOM-1-N8
U3: DS3231SN#; SOIC127P1032X265-16N
U4: MAX17048G+T10; SON50P200X200X80-9N

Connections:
3V3: C1_BAT2.1, C3.+, C9.1, D7.2 (ANODE), IC1.2 (VDD), IC4.5 (VOUT), J3.2, J4.P4 (VDD), Q2.3 (D), R1.1, R1_PINH1.2, R2_PINH1.2, R5.2, R6.2, R7.2, R8.2, R9.2, R10.2, R_BOOT.1, R_CHANGE.1, R_CL1.1, R_RESET.1, TP16.TP, U1.3 (!WP!(IO2)), U1.7 (!HOLD!/!RESET!(IO3)), U1.8 (VCC), U2.2 (3V3), U3.2 (VCC)
32KHZ: R2_PINH1.1, U2.9 (IO1), U3.1 (32KHZ)
DN: D1.4 (I/O2_2), J2.A7, J2.B7
DP: D1.6 (I/O1_2), J2.A6, J2.B6
EPD_3V3: C7.1, EPD_C5.1, J1.15, J1.16, L1.2, Q2.2 (S), TP17.TP
EPD_3V3_C: Q2.1 (G), R_CL1.2, TP13.TP, U2.18 (IO20)
EPD_BUSY: J1.9, TP9.TP, U2.26 (IO3)
EPD_CS: D6.2, J1.12, R9.1, TP10.TP, U2.11 (IO10)
EPD_DC: J1.11, TP11.TP, U2.5 (IO5)
EPD_RST: J1.10, TP12.TP, U2.21 (IO23)
FLASH_CS: D9.2, R5.1, U1.1 (!CS), U2.12 (IO11)
GDR: J1.2, Q3.1 (G), R4.1
GND: BOOT_BUTTON.1, BOOT_BUTTON.2, C1.2, C1_BAT.2, C1_BAT1.2, C1_BAT2.2, C2.2, C2_BAT.2, C3.-, C4_USB.2, C5.2, C5_USB.2, C6.2, C7.2, C8.2, C9.2, C10.2, C10_SUPERCAP.1, CHANGE_BUTTON.1, CHANGE_BUTTON.2, C_DELAY.2, D1.2 (GND), D3.1 (K), D6.1, D8.1, D9.1, D10.1, D11.1, D12.1, EPD_C5.2, EPD_C6.2, EPD_C7.2, EPD_C8.2, EPD_C9.2, EPD_C10.2, EPD_C11.2, EPD_C12.2, IC1.3 (GND), IC4.2 (VSS), J1.17, J1.MP1, J1.MP2, J2.A1, J2.A12, J2.B1, J2.B12, J2.MP1, J2.MP2, J2.MP3, J2.MP4, J3.1, J4.G1 (GND_1), J4.G2 (GND_2), J4.G3 (GND_3), J4.G4 (GND_4), J4.P6 (VSS), MCP737831.2 (VSS), R1_PWRUSB.2, R2.1, R2-USB.2, R2-USB1.1, R2_BAT.1, R4.2, RESET_BUTTON.1, RESET_BUTTON.2, SENSOR2.1 (GND), SENSOR2.5 (SDO), SENSOR2.7 (GND), SJ1.1, TP4.TP, TP5.TP, U1.4 (GND), U1.9 (EXP), U2.1 (GND), U2.28 (GND), U2.29_1 (GND), U2.29_2 (GND), U2.29_3 (GND), U2.29_4 (GND), U2.29_5 (GND), U2.29_6 (GND), U2.29_7 (GND), U2.29_8 (GND), U2.29_9 (GND), U3.13 (GND), U4.1 (CTG), U4.4 (GND), U4.6 (QSTRT), U4.9 (EP)
I2C_PW: C1.1, C2.1, R1_PINH.2, R2_PINH.2, SENSOR2.2 (CSB), SENSOR2.6 (VDDIO), SENSOR2.8 (VDD), U2.17 (IO19)
INT_RTC: R1_PINH1.1, TP15.TP, U2.8 (IO0), U3.3 (SQW/!INT)
IO/BOOT: BOOT_BUTTON.3, BOOT_BUTTON.4, C6.1, R_BOOT.2, U2.15 (IO9)
IO/CHANGE: C10.1, CHANGE_BUTTON.3, CHANGE_BUTTON.4, R_CHANGE.2, U2.23 (IO15)
MISO: D12.2, J4.P7 (DAT0), R8.1, TP6.TP, U1.2 (DO(IO1)), U2.27 (IO2)
MOSI: D11.2, J1.14, J4.P3 (CMD), R7.1, TP7.TP, U1.5 (DI(IO0)), U2.7 (IO7)
unnamed: C1_BAT1.1, D2.1 (CATHODE), IC4.1 (VIN), IC4.3 (CE), Q1.2 (S)
unnamed: EPD_C12.1, J1.24
unnamed: J2.A5, R2-USB1.2
unnamed: CHG_LED.C, R1_BAT.2
unnamed: C4.1, D3.2 (A), D4.1 (K)
unnamed: MCP737831.1 (STAT), R1_BAT.1
unnamed: MCP737831.5 (PROG), R2_BAT.2
unnamed: EPD_C11.1, J1.23
unnamed: J2.B5, R2-USB.1
unnamed: EPD_C10.1, J1.22
unnamed: EPD_C9.1, J1.21
unnamed: EPD_C8.1, J1.20
unnamed: EPD_C7.1, J1.19
unnamed: EPD_C6.1, J1.18
unnamed: C_DELAY.1, IC1.5 (CT)
unnamed: R1.2, U2.10 (IO8)
unnamed: EPD_C1.2, EPD_C2.2, J1.8
unnamed: EPD_C1.1, J1.4
unnamed: EPD_C2.1, J1.5
unnamed: D7.1 (CATHODE), R_CAPACITOR.2
unnamed: C8.1, C10_SUPERCAP.2, R_CAPACITOR.1
PREVGH: D5.1 (K)
PREVGL: D4.2 (A)
RESE: J1.3, Q3.2 (S), R3.1
RESE': R2.2, R3.2, SJ1.2
RESET: C5.1, IC1.1 (VOUT), RESET_BUTTON.3, RESET_BUTTON.4, R_RESET.2, U2.3 (EN)
RTC_RST: U2.16 (IO18), U3.4 (!RST)
RX: TP2.TP, U2.24 (RXD0/GPIO17)
SCK: D10.2, J1.13, J4.P5 (CLK), R6.1, TP8.TP, U1.6 (CLK), U2.6 (IO6)
SCL: J3.4, R2_PINH.1, SENSOR2.4 (SCK), U2.20 (IO22), U3.16 (SCL), U4.7 (SCL)
SDA: J3.3, R1_PINH.1, SENSOR2.3 (SDI), U2.19 (IO21), U3.15 (SDA), U4.8 (SDA)
SRC: C4.2, D5.2 (A), L1.1, Q3.3 (D)
SS_SD: D8.2, J4.P2 (CD/DAT3), R10.1, U2.4 (IO4)
TX: TP1.TP, U2.25 (TXD0/GPIO16)
USB_D+: D1.1 (I/O1_1), U2.14 (IO13)
USB_D-: D1.3 (I/O2_1), U2.13 (IO12)
VBAT: C2_BAT.1, MCP737831.3 (VBAT), Q1.3 (D), TP3.TP, U4.2 (CELL), U4.3 (VDD)
VBUS: C1_BAT.1, C4_USB.1, C5_USB.1, CHG_LED.A, D1.5 (VBUS), D2.2 (ANODE), MCP737831.4 (VIN), PFMF.050.1.2, Q1.1 (G), R1_PWRUSB.1, TP14.TP
VRTC: U3.14 (VBAT)
VUSB: J2.A4, J2.A9, J2.B4, J2.B9, PFMF.050.1.1

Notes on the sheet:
USB C connector & ESD protection
LDO Voltage Regulator
SD Card
Display Type Selector
E-Paper Drive Circuit
Li-Po Battery Charging Controller
ESP32 C6
E-Paper Display Header
EPD Power
Environmental Sensor BME688
Voltage Supervisor + Reset & Boot / IO Button
Battery Charge Level
RTC Module DS3231SN
Test Pads
Qwiic / Stemma QT
SPI ESD Protection Lines
External NOR Flash 64MB
OpenBook Schematic
drawn by: Matei Mantu

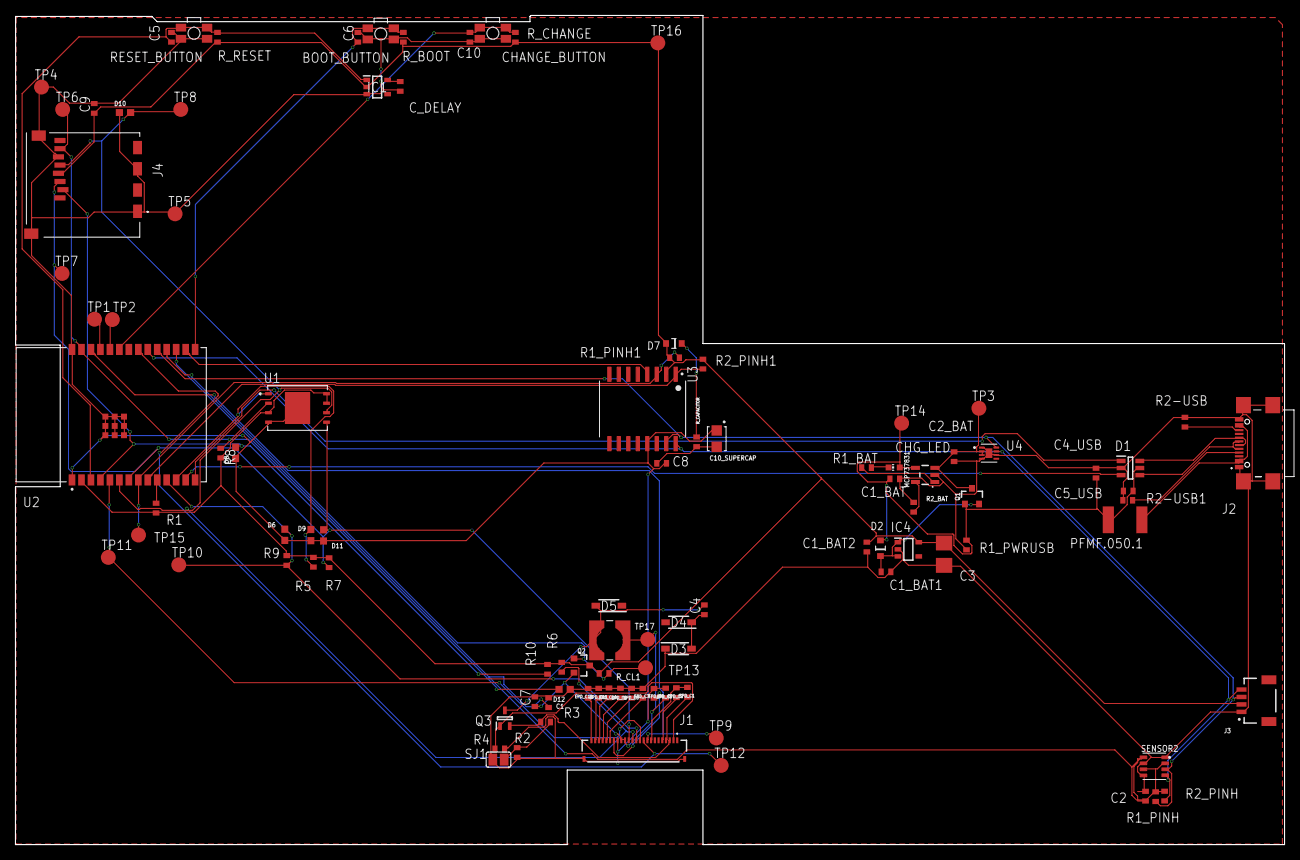
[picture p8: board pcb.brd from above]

Board: 2 copper layers, 170.2 x 111.2 mm, 103 parts (0 on the bottom side), 56 nets.

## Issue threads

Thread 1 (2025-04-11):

Schematic Pin Error

Sabin1133, 2025-04-11:
GND Pin overwritten with more than one signal.

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

I suggest separating the signal by adding one more GND component.

mtimaN, 2025-04-13:
Thanks for the issue!

Closed 2025-04-13.

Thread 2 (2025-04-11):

PCB Wire Error

Sabin1133, 2025-04-11:
PCB wire stub not connected.

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

Just a simple manual routing fixes the problem in no time.

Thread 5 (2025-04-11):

Minor silkscreen issues

Sabin1133, 2025-04-11:
Near some components the labels are a bit off and can not be seen properly.

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

I suggest scaling them up or down for better quality and aligning them with their respective components.

mtimaN, 2025-04-13:
Thanks. Solved!

Closed 2025-04-13.

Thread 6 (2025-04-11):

PCB wires width

Sabin1133, 2025-04-11:
The power routes seem to be 0.3mm wide but are not.

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

I suggest rerouting the components by creating net classes for each type of signal and then adding a `wire width` rule for each net class in order to properly place the power routes.

mtimaN, 2025-04-13:
Good catch!

Closed 2025-04-13.

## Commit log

2025-04-06 Add project
    [pcb.brd, schematic.sch]
2025-04-06 Update README.md
    Add BOM
2025-04-06 Add ESP32 schematic image
2025-04-06 Update README.md
    Clear BOM
2025-04-06 Update README.md
    Add detailed pin descriptions
2025-04-11 Update README.md
    Add Power consumption estimates

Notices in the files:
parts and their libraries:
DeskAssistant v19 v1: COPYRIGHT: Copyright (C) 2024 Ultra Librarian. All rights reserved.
